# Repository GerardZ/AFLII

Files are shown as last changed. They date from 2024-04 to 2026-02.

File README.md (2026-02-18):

# AFLII

## A Faster Lcd I2c Interface

### **So what is this ?**

This is a replacement for the PCF8574 LCD-interface board, which is pin but not API compatible.

It is faster and less cpu consuming for the host because the used AtTiny414 takes care of low-level data handling, besides BUSY-flag is used instead of wait-routines which allows for faster and more easy writing the display.

### **And why should i use this ?**

For me this was a getting-to-know the AtTiny414 project, but it also has some advantages above the PCF8574-solution.

Pro\`s:

*   faster, steering the LCD module is off-loaded from the host. Benchmarked @>300 lines/second
*   more efficient by using BUSY instead of wait
*   easy API, in essence just push line number and string over i2c. Uses less memory and cpu on host
*   cheaper (at least @Mouser, a AtTiny814 costs around 55 cents, where a PCF8574 does 120 cents)
*   Backlight dimming !   
*   you could incorporate some custom routines
*   pin free for user
*   you might learn from this :)

Con\`s:

*   the rest of the world uses PCF8574
*   there\`s no ready-build hardware available
*   API differs from the PCF solution

Todo:

*   The WaitBusy should hold I2C communication by clock stretching. We now still need a delay @host side.
*   Better PCB design
*   More & clearer examples

Schema:

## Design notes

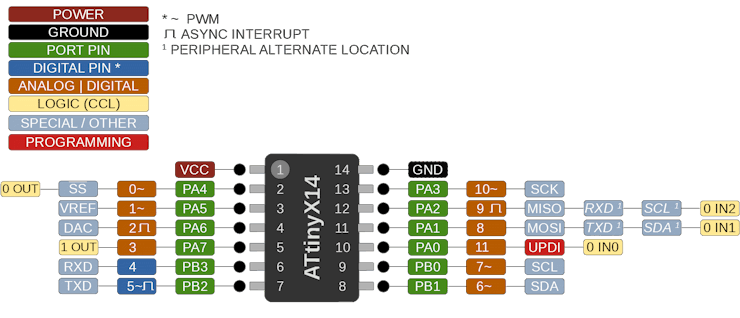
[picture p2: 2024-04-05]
Docs/Images/AtTiny414_pinout.png

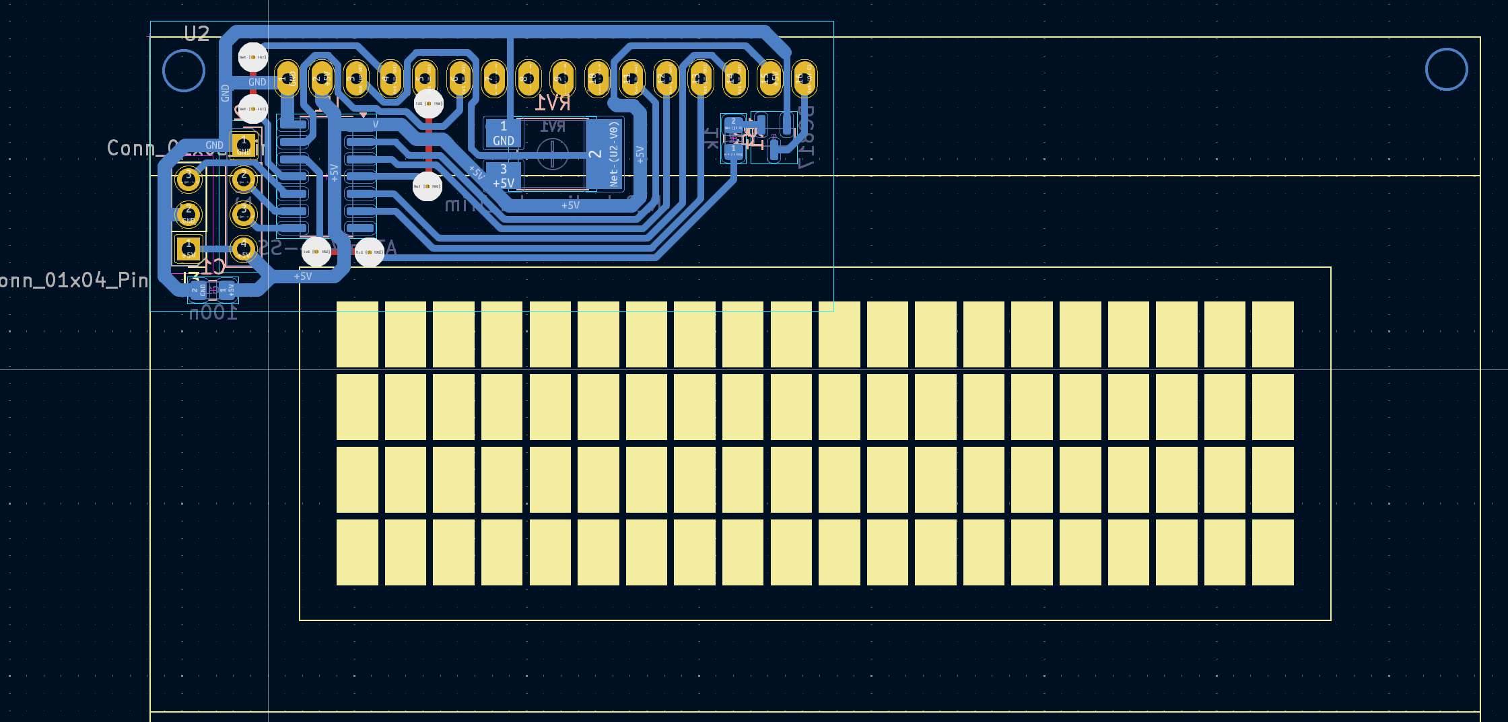
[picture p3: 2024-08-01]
Docs/Images/PCB.png

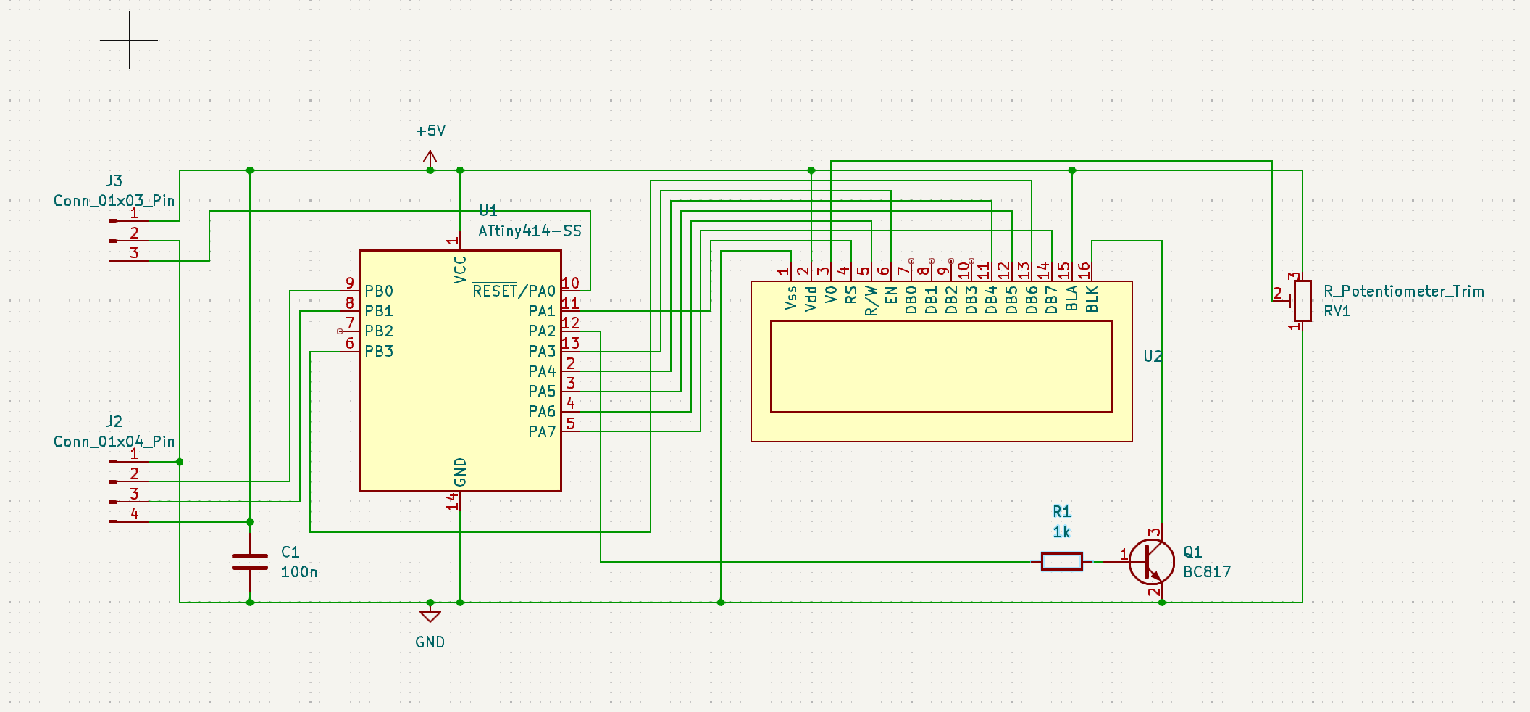
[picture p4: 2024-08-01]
Docs/Images/schema.png

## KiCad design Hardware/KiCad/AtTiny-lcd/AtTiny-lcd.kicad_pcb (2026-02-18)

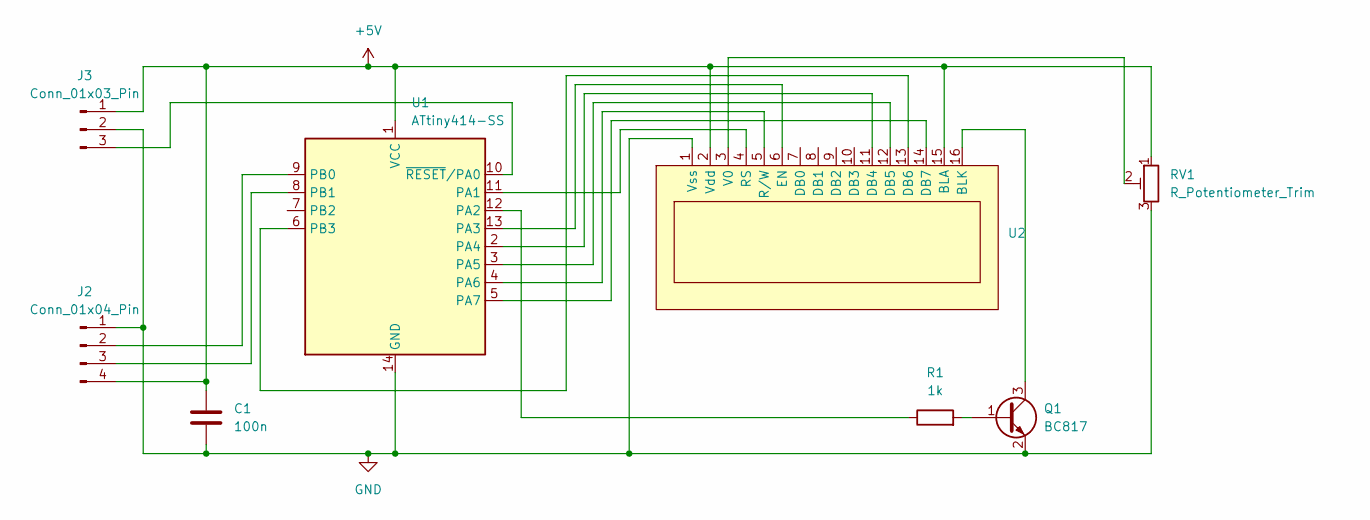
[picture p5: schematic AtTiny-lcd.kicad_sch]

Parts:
C1: 100n; C_0805_2012Metric_Pad1.18x1.45mm_HandSolder
J2: Conn_01x04_Pin; PinHeader_1x04_P2.54mm_Vertical
J3: Conn_01x03_Pin; PinHeader_1x03_P2.54mm_Vertical
Q1: BC817; SOT-23
R1: 1k; R_0805_2012Metric_Pad1.20x1.40mm_HandSolder
RV1: R_Potentiometer_Trim; Potentiometer_SMD_EBay_10k
U1: ATtiny414-SS; SOIC-14_3.9x8.7mm_P1.27mm
U2: LCD2008

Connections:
+5V: C1.1, J2.4, J3.1, RV1.1, U1.1 (VCC), U2.2 (Vdd), U2.15 (BLA)
GND: C1.2, J2.1, J3.2, Q1.2 (E), RV1.3, U1.14 (GND), U2.1 (Vss)
unnamed: J2.2, U1.9 (PB0)
unnamed: J2.3, U1.8 (PB1)
unnamed: J3.3, U1.10 (~RESET/PA0)
unnamed: Q1.1 (B), R1.2
unnamed: Q1.3 (C), U2.16 (BLK)
unnamed: U1.11 (PA1), U2.4 (RS)
unnamed: R1.1, U1.12 (PA2)
unnamed: U1.13 (PA3), U2.6 (EN)
unnamed: U1.2 (PA4), U2.11 (DB4)
unnamed: U1.3 (PA5), U2.12 (DB5)
unnamed: U1.4 (PA6), U2.5 (R/W)
unnamed: U1.5 (PA7), U2.14 (DB7)
unnamed: U1.6 (PB3), U2.13 (DB6)
unnamed: RV1.2, U2.3 (V0)

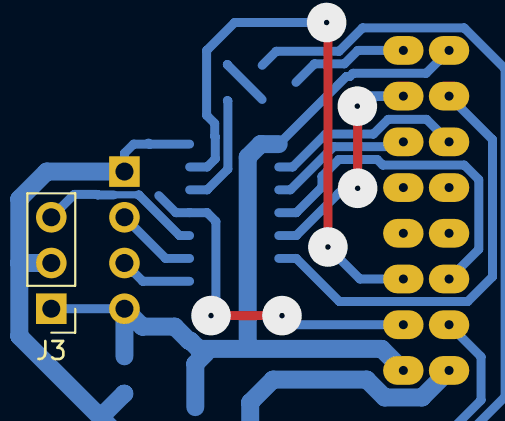
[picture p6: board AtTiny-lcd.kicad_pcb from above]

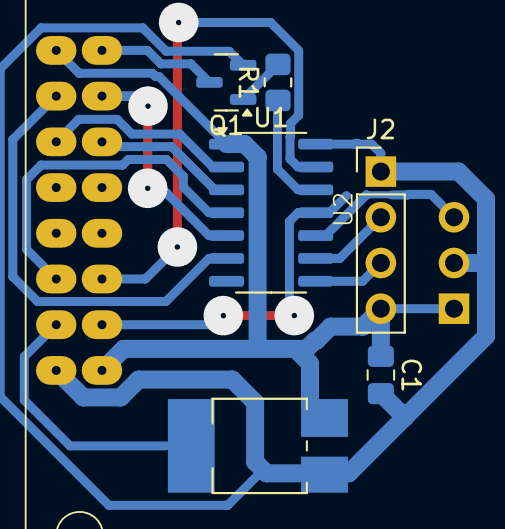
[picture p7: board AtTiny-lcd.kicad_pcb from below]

Board: 2 copper layers, 8 parts (7 on the bottom side), 16 nets.

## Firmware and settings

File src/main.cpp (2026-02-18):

#include <Arduino.h>
#include <avr/interrupt.h>
#include <avr/io.h>

#include "lcdmod.h"

// I2C Slave

#include <Wire.h>

void DoLCD();

struct I2CBUF
{
  volatile uint8_t len;
  volatile uint8_t command;
  volatile uint8_t data[20];
};

volatile I2CBUF i2cBuffer;

void receiveDataWire(int numBytes)
{
  i2cBuffer.len = numBytes - 1; // -1 byte0 is command
  i2cBuffer.command = Wire.read();

  for (uint8_t i = 0; (i < numBytes - 1) && (i < 20); i++)
  {
    i2cBuffer.data[i] = Wire.read();
  }

  // WaitBusy();
}

void transmitDataWire()
{
#if !defined(MILLIS_USE_TIMERNONE)
  uint32_t ms = millis();
#else
  uint32_t ms = 123456789UL; // placeholder - there's no millis to send because it's disabled.
#endif
  Wire.write((uint8_t)ms);
  Wire.write((uint8_t)(ms >> 8));
  Wire.write((uint8_t)(ms >> 16));
  Wire.write((uint8_t)(ms >> 24));
}

void setupI2C()
{
  Wire.onReceive(receiveDataWire);  // give the Wire library the name of the function, this is handled in interrupt so keep it short
  Wire.onRequest(transmitDataWire); // same as above, but master read event, this is handled in interrupt so keep it short
  Wire.begin(0x21);                 // join i2c bus with address 0x54
}

// I2C Slave end



void demo(){
   // just for demonstration actually...
  LCD_createChar(0, Smiley);
  LCD_createChar(1, Bell);
  LCD_createChar(2, Heart);
  
  LCD_Write("Hello world!");
  LCD_Write("2nd line...", 2);

  LCD_Write("3rd line...", 3);
  LCD_SendData(0);
  LCD_SendData(1);
  LCD_SendData(2);
  LCD_Write("4th line...", 4);

}

void setup()
{
  LCD_Init();

  setupI2C();

  SetBacklightDimInt(80);
  //SetBacklightDimTimer(100);

  demo();
}

// uint8_t line[16];
volatile uint16_t count = 0;

void WriteCount(uint16_t inCount)
{
  const int q[] = {10000, 1000, 100, 10, 1};
  uint16_t count;
  uint8_t zero = ' ';
  count = inCount;
  uint8_t dec;

  for (uint8_t i = 0; i < 4; i++)
  {
    if (count >= q[i])
    {
      dec = count / q[i];
      count -= dec * q[i];
      dec += 0x30; // convert number to asc value
      zero = '0';
    }
    else
      dec = zero;
    LCD_SendData(dec);
  }
  LCD_SendData(count + 0x30);
}

void DoLCD()
{
  if (i2cBuffer.command == NOP)
    return;

  if (i2cBuffer.command >= LINE1 && i2cBuffer.command <= LINE4)
    LCD_Write(i2cBuffer.data, i2cBuffer.len, i2cBuffer.command, 0);

  if (i2cBuffer.command == CLEAR)
  {
    LCD_Clear();
    // delay(50);
  }

  if (i2cBuffer.command == BL_OFF)
  {
    LCD_Backlight(0);
    // LCD_Write("BL off...", 3);
  }

  if (i2cBuffer.command == BL_ON)
  {
    LCD_Backlight(255);
    // LCD_Write("BL on...", 3);
  }

  if (i2cBuffer.command >= SET_CUSTOM_CHAR0 && i2cBuffer.command <= SET_CUSTOM_CHAR7)
  {
    LCD_createChar(i2cBuffer.command - SET_CUSTOM_CHAR0, const_cast<uint8_t *>(i2cBuffer.data));
    // delay(10);
  }

  i2cBuffer.command = NOP;
}

void loop()
{
  count++;

  LCD_Write("Count: ", 4);
  WriteCount(count);

  DoLCD();
}

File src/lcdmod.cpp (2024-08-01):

#include "lcdmod.h"

/*
LCD-routines, use a AtTiny414 to interface LCD
We use 4-bit communication to preserve pins
Maybe connect contrast to DAC !
Build I2C-slave

Features:
  - check BUSY
  - all working 4x20
  - optimised for speed (writes ca. 1000 lines/sec)
*/

volatile boolean LCDBusy;

volatile int8_t pwmValue = 15;
volatile int8_t pwmCount;

// some demo characters
byte Smiley[] = {
    B00000,
    B10001,
    B00000,
    B00000,
    B10001,
    B01110,
    B00000,
    B00000,
};

byte Heart[] = {
    B00000,
    B01010,
    B11111,
    B11111,
    B01110,
    B00100,
    B00000,
    B00000};

byte Bell[] = {
    B00100,
    B01110,
    B01110,
    B01110,
    B11111,
    B00000,
    B00100,
    B00000};

ISR(TCA0_OVF_vect)
{ // backlight ISR
    pwmCount++;
    if (pwmCount > 31)
        pwmCount = 0;

    digitalWrite(LCD_BL, pwmValue > pwmCount);

    // Clear the interrupt flag
    TCA0.SINGLE.INTFLAGS = TCA_SINGLE_OVF_bm;
}

void setupBLInterrupt()
{
    // Disable interrupts
    cli();

    // Set the TCA0 to Normal mode (by default it's in Split mode)
    TCA0.SINGLE.CTRLD = 0;
    TCA0.SINGLE.CTRLB = 0;                    // Normal mode
    TCA0.SINGLE.CTRLC = 0;                    // No force compare
    TCA0.SINGLE.CTRLECLR = TCA_SINGLE_CMD_gm; // No command

    // Set the period (8 MHz / 64 prescaler / 1000 Hz - 1)
    TCA0.SINGLE.PER = (8000000 / 64 / 3200) - 1;

    // Enable overflow interrupt
    TCA0.SINGLE.INTCTRL = TCA_SINGLE_OVF_bm;

    // Set the prescaler and enable the timer
    TCA0.SINGLE.CTRLA = TCA_SINGLE_CLKSEL_DIV64_gc | TCA_SINGLE_ENABLE_bm;

    // Enable global interrupts
    sei();
}

void SetBacklightDimInt(uint8_t dimValue)
{
    pwmValue = dimValue / 8;
}

void setupTimerPWM2()
{

    cli(); // Disable interrupts
    // TCA0.SINGLE.CTRLB = TCA_SINGLE_WGMODE_SINGLESLOPE_gc; // Set the waveform generation mode to Single Slope PWM

    // Enable Compare Channel 2 (WO2)
    // TCA0.SINGLE.CTRLB |= TCA_SINGLE_CMP2EN_bm;

    TCA0.SINGLE.CTRLB = TCA_SINGLE_WGMODE_SINGLESLOPE_gc | TCA_SINGLE_CMP2EN_bm;

    TCA0.SINGLE.EVCTRL &= ~(TCA_SINGLE_CNTEI_bm);

    // Set the period (top value)
    TCA0.SINGLE.PERBUF = 0xFF;

    // Set the duty cycle for Compare Channel 2 (50% duty cycle)
    TCA0.SINGLE.CMP2 = 0x80;

    // Select the clock source and start the timer (divided by 64)
    // TCA0.SINGLE.CTRLA = TCA_SINGLE_CLKSEL_DIV64_gc | TCA_SINGLE_ENABLE_bm;
    TCA0.SINGLE.CTRLA = 7;

    // Enable interrupts
    sei();

    PORTA.DIRSET = PIN2_bm;
}

#if defined(MILLIS_USE_TIMERA0) || defined(__AVR_ATtinyxy2__)
#error "This sketch takes over TCA0, don't use for millis here.  Pin mappings on 8-pin parts are different"
#endif

void setupTimerPWM()
{
    // PA2...

    
    PORTA.DIRSET = PIN2_bm;

    // Disable interrupts
    cli();

    takeOverTCA0();

    // Set the waveform generation mode to Single Slope PWM
    TCA0.SINGLE.CTRLB = TCA_SINGLE_WGMODE_SINGLESLOPE_gc;

    // Enable Compare Channel 2 (WO2)
    TCA0.SINGLE.CTRLB |= TCA_SINGLE_CMP2EN_bm;

    // Set the period (top value)
    TCA0.SINGLE.PER = 0xFF;

    // Set the duty cycle for Compare Channel 2 (50% duty cycle)
    TCA0.SINGLE.CMP2 = 0x80;

    // Select the clock source and start the timer (divided by 64)
    TCA0.SINGLE.CTRLA = TCA_SINGLE_CLKSEL_DIV64_gc | TCA_SINGLE_ENABLE_bm;

    // Enable interrupts
    sei();
}

void SetBacklightDimTimer(uint8_t dimValue)
{
    TCA0.SINGLE.CMP2 = dimValue;
}

void DataBusInput()
{
    /*
    Sets D4-D7 as input, then sets LCD_RW high (read).
    */

    pinMode(LCD_D4, INPUT); // D4-D7 input
    pinMode(LCD_D5, INPUT);
    pinMode(LCD_D6, INPUT);
    pinMode(LCD_D7, INPUT);

    digitalWrite(LCD_RW, HIGH); // SET READ MODE, set LCD databus as output
}

void DataBusOutput()
{
    /*
    Sets LCD_RW low, then sets D4-D7 as output
    */

    digitalWrite(LCD_RW, LOW); // SET WRITE MODE, actually set LCD databus as input.

    pinMode(LCD_D7, OUTPUT); // D4-D7 output
    pinMode(LCD_D6, OUTPUT);
    pinMode(LCD_D5, OUTPUT);
    pinMode(LCD_D4, OUTPUT);
}

void LCD_createChar(uint8_t location, uint8_t charmap[])
{
    /*
    Writes 8 bytes in the character memory @location.
    The LCD has 8 user defined 8-byte memory locations @0x40 - 0x47 in which
    it can store user defined characters

    example:
        LCD_createChar(
                        3,
                        {   B00000,
                            B01010,
                            B11111,
                            B11111,
                            B01110,
                            B00100,
                            B00000,
                            B00000 }
                        );
    // which will create a heart character on location @3

    // To send it:
    LCD_Write("This is a heart: ", 2);  // write on line 2, note that cursor stays at last char
    LCD_SendData(3);                    // will actually write char from user memory #3

    */

    location &= 0x7; // we only have 8 locations 0-7

    LCD_SendCommand(LCD_SETCGRAMADDR | (location << 3));

    for (int i = 0; i < 8; i++)
    {
        LCD_SendData(charmap[i]); // call the virtual write method
    }
}

bool checkBit(byte targetByte, int position)
{
    return (targetByte & (1 << position)) != 0;
}

void LCD_Clear() // clear Screen
{
    LCD_SendCommand(LCD_CLEAR);
}

void LCD_Backlight(uint8_t value)
{
    if (value != 0)
        digitalWrite(LCD_BL, HIGH);
    else
        digitalWrite(LCD_BL, LOW);
}

void LCD_Init() // Reset, Init & Clear LCD
{
    /*
    Set appropriate pins in needed IO mode,
    Send init to LCD
    Clear LCD
    */

    pinMode(LCD_RS, OUTPUT);
    pinMode(LCD_EN, OUTPUT);
    pinMode(LCD_BL, OUTPUT);
    pinMode(LCD_RW, OUTPUT);
    DataBusOutput();

    LCD_SendCommand(LCD_Mode_8Bit);      // Must initialize to 8-line mode at first
    LCD_SendCommand(LCD_Mode_4Bit);      // Then initialize to 4-line mode
    LCD_SendCommand(LCD_Mode_2Line_5x7); // 2 Lines & 5*7 dots
    LCD_SendCommand(LCD_On_CursorOff);   // Enable display without cursor
    LCD_Clear();

    setupBLInterrupt();
    //setupTimerPWM();

    //analogWrite(LCD_BL, 18); // 50% duty cycle
}

void LCD_SetCursor(uint8_t x, uint8_t y)
{
    y &= 3;
    const uint8_t startLine[] = {LCD_line0_addr, LCD_line1_addr, LCD_line2_addr, LCD_line3_addr}; // mem map for lines: ln1: 0x00, ln2: 0x40, ln3: 0x14, ln4: 0x54
    LCD_SendCommand(LCD_SetCursorPosition + startLine[y] + x);                                    // Move cursor
}

void LCD_Delay1()
{
    delay(1);
}
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

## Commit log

2024-04-05 KiCad files added
    [AtTiny-lcd.kicad_pcb, AtTiny-lcd.kicad_sch]
2024-04-05 cleanup #1
    [AtTiny-lcd.kicad_sch]
2024-07-30 Backlight dimming
    [AtTiny-lcd.kicad_pcb, AtTiny-lcd.kicad_sch]
2024-07-31 PCB updated
    [AtTiny-lcd.kicad_pcb, AtTiny-lcd.kicad_sch]
2024-08-01 updated PCB dimming through ISR
    [AtTiny-lcd.kicad_pcb, AtTiny-lcd.kicad_sch]
2024-08-01 PNG of schema and PCB
